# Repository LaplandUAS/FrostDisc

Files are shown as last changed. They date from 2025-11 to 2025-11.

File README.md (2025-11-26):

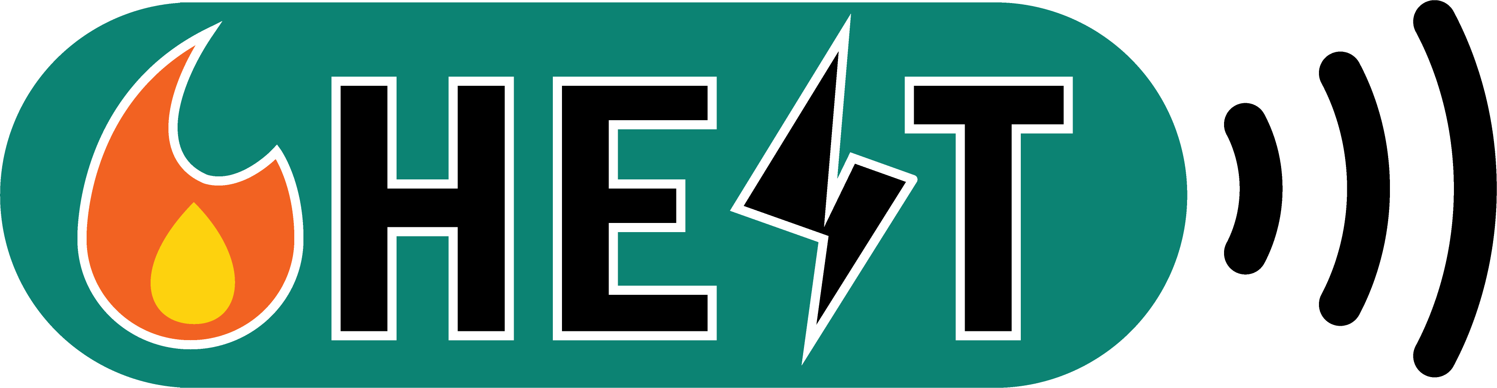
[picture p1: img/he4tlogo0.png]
He4T Logo Project logo

# FrostDisc
HE4T ForstDisc
Road embedded ultra-low power temperature gradient sensor built with wireless LoRaWAN technology. This repository contains the system firmware, and printed circuit board designs.
The device features:
* 4x [TMP117](https://www.ti.com/lit/ds/symlink/tmp117.pdf?ts=1762762775582) High-Accuracy temperature sensors.
* MultiTech [xDot](https://multitech.com/wp-content/uploads/86002182.pdf) LoRaWAN module.
* [MSP430G2231](https://www.ti.com/lit/ds/symlink/msp430g2231-q1.pdf?ts=1762703573675) microcontroller.

The device's energy source also features a battery pack and a super capacitor power reserve maintained by an [Epishine](https://www.epishine.com/) PV-cell. The assembly is embedded into a durable resin cast.

Mockup 3d render Frostdisc mockup

## Hardware setup
Required tools and hardware:
* Soldering iron
* USB-UART adapter
* MSP-FET programmer
* FrostDisc MK.4

### Radio
First, connect your USB-UART adapter to the edge connector on the FrostDisc MK.4 board. The edge is an [AVX10](https://datasheets.kyocera-avx.com/OpenEndedCardEdge_00-9159.pdf)-edge connector, but temporary soldering or pogo pins work fine too.
Follow this pinout (fig.1). The diagram shown connects to the top-layer of the edge connector.
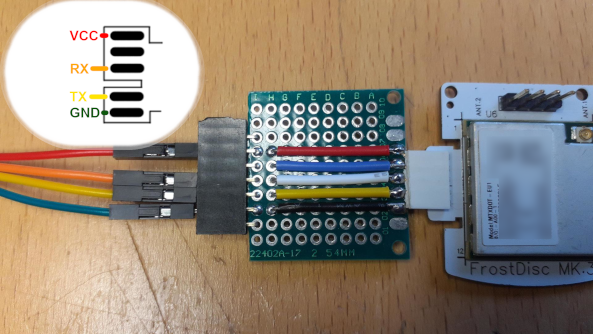
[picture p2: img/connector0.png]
UART connection AVX10 adapter board

Open a serial terminal software (Like PuTTY or CoolTerm), and connect to your your USB-UART adapter with these parameters:
| Parameter | Value |
| --- |:---:|
| Baudrate | 115200 |
| Data Bits | 8 |
| Parity | None |
| Stop Bits | 1 |

Confirm proper connection with:
```
>ATI
ATIMultiTech xDot
Firmware : 4.1.32-mbed60800
Library  : 4.1.30-mbed60800
MTS-Lora : 4.1.21-mbed60800

OK
```
> [!WARNING]
> Skip commands marked with '*' before writing parameters if you intend to test your connection manually first!
> Only apply these commands after you've checked your connection. The command order given below is is for bulk-programming without any manual testing.

Apply these parameters in this order:

| Parameter |  Description |
| --- |:---:|
| AT+DI? | DevEUI, write down for your LoRaWAN provider |
| AT+NA=<Your DevAddr> | Match with your LoRaWAN provider (HEX-tring) |
| AT+DSK=<Your AppSKey> | Match with your LoRaWAN provider (HEX-tring) |
| AT+NSK=<Your NSK> | Match with your LoRaWAN provider (HEX-tring) |
| AT+NJM=0 | Sets radio in ABP mode |
| AT+WP=6,0,1 | Sets wakeup pin * |
| AT+WM=1 | Sets wakeup mode to "On interrupt" * |
| ATE0 | Disable echo (optional) * |
| AT&W | Write parameters |
| ATZ | Soft reset |

Please refer to your LoRaWAN network service provider's instructions for pairing, or your gateway's user manual if you have your own.

Further information on the xDot AT-syntax can be found [here](https://multitech.com/wp-content/uploads/S000768-xDot-AT-Command-Guide.pdf).

You can manually test your connection with your LoRaWAN network of choice after configuring both ends by issuing the following AT command:

```
>AT+SENDB=DEADBEEF

OK
```
Note that in order to comply with EU868 restrictions, the transmission channel will be disabled for a few minutes after each `AT+SEND`.

### MCU

The MCU firmware is uploaded using an MSP-FET programmer for TexasInstruments MSP430-based microcontrollers. You can also use the debug-part of an MSP430 Launchpad development board.
The firmware is flashed using the CodeComposer Studio IDE.

Hook up your programmer of choice to the FrostDisc MK.4 header J.3 (fig.2)
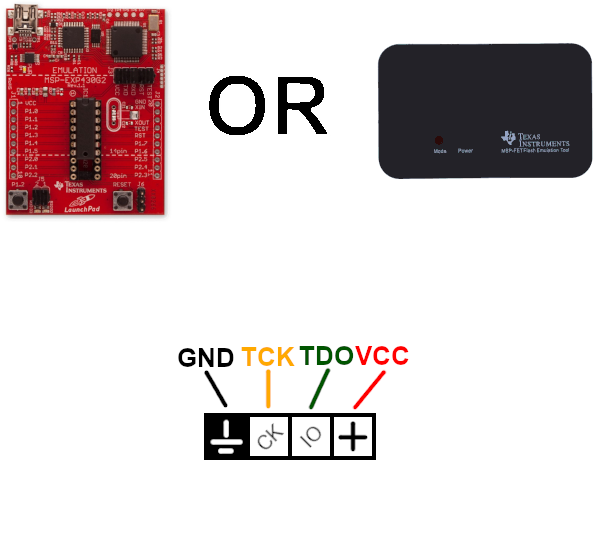
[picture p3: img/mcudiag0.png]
Programmer hookup MCU hookup diagram


In CodeComposer Studio, right click the active project and choose "Properties" (fig.3).

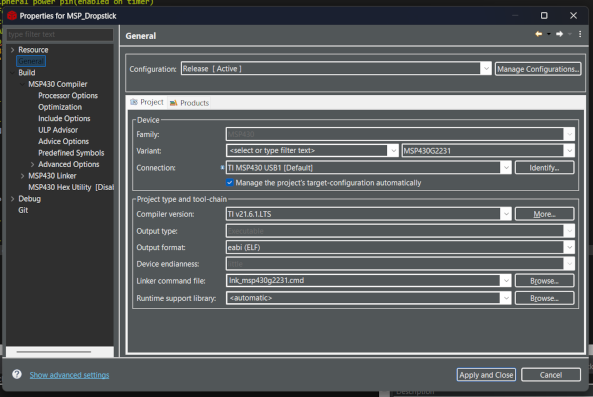
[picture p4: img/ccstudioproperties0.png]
Properties dialog Project properties

In the General settings, make sure that the device variant is "MSP430G2231". Then plug your programmer to your PC's USB-port and click "Identify". After the debugger identifies your programmer, it should show up in the drop down menu as `TI MSP430 Launchpad`, or `TI MSP430 USB1`.
For the linker command file, click browse and use the .cmd file provided in the 'src' directory. Click apply and Close.

Next, click the "Flash" icon on the top left corner (fig.4)

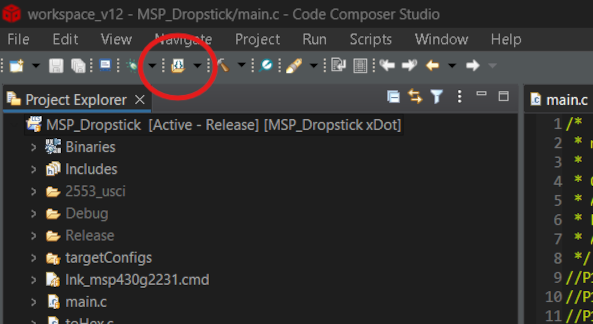
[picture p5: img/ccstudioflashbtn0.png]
Flash icon Click flash


Disconnect the programmer from the FrostDisck MK.4 once the firmware flash completes.

Next, solder a bridge over JP1, bridging it's topmpost and middle pad. Bridge the SJ2 pads (fig.5)

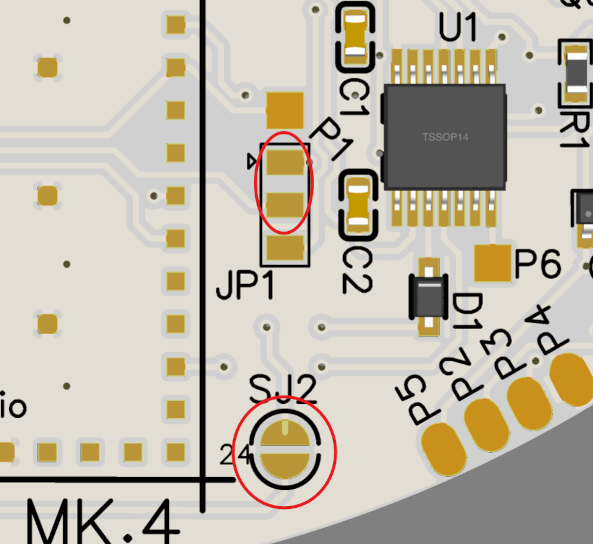
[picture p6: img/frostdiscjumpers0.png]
Solder jumpers Solder jumper bridges


### Initial tests
Before connecting the battery pack and temperature sensors, test if the system transmits data properly. Hook up a 3.3V power supply to the VCC and GND pins on the programming header and monitor your LoRaWAN gateway traffic. A small antenna may be needed for your radio if the RSSI is poor. After 10-minutes, you should be receiving the first packets from your device, which should be in a hexadecimal string format. The payload consists of 4 16-bit temperature readings followed by a single 16-bit value indicating the current battery charge.

Example payload:
`data: 0AFF0AFF0AFF0AFF3024D`
| Sensor 1 | Sensor 2 | Sensor3 | Sensor 4 | Core VCC |
| --- |:---:|:---:|:---:|:---:|
| 0AFF | 0AFF | 0AFF | 0AFF | 024D |

All the sensor readings will display the same value since they're not connected. For decoding payloads, we have ([a terminal program]repository here) for interfacing with an MQTT broker.

### Sensors and Battery pack

After confirming succesful downlink, disconnect the device from your power supply and solder thin 24-26AWG wires to the TMP117 sensor module (fig.6).

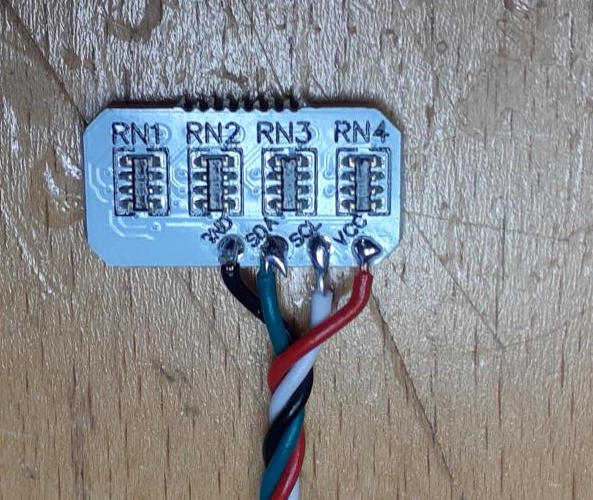
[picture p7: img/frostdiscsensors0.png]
TMP117 module TMP117 subassembly


Take note of the labels above the pads.
Solder to the corresponding pads on the FrostDisc MK.4 board (fig.7).

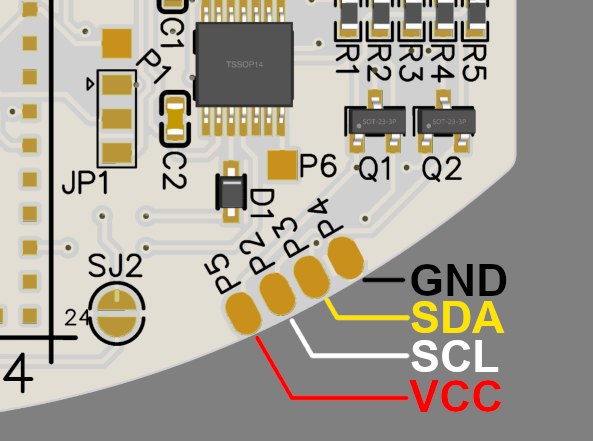
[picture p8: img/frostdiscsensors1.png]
I2C Bus TMP117 bus


Mount the battery pack on the J1 connector on the top edge of board, and attach the assembly to the 3D-printed cage.

---------


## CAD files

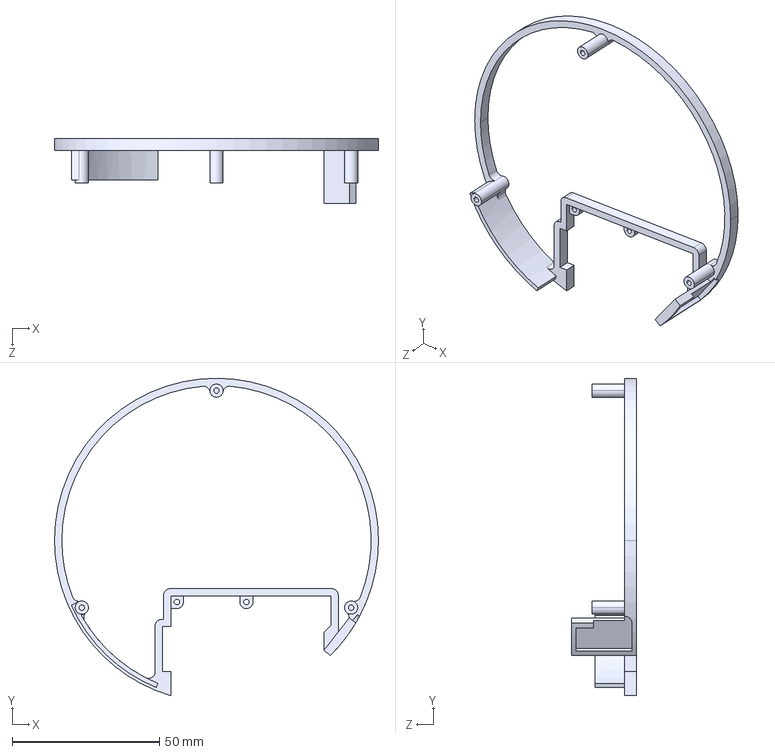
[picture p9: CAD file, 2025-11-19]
cad/cagehull.STEP
110.0 x 107.8 x 22.0 mm

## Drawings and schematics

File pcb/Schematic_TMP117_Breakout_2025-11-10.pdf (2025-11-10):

TMP117-0x48 | TMP117-0x49

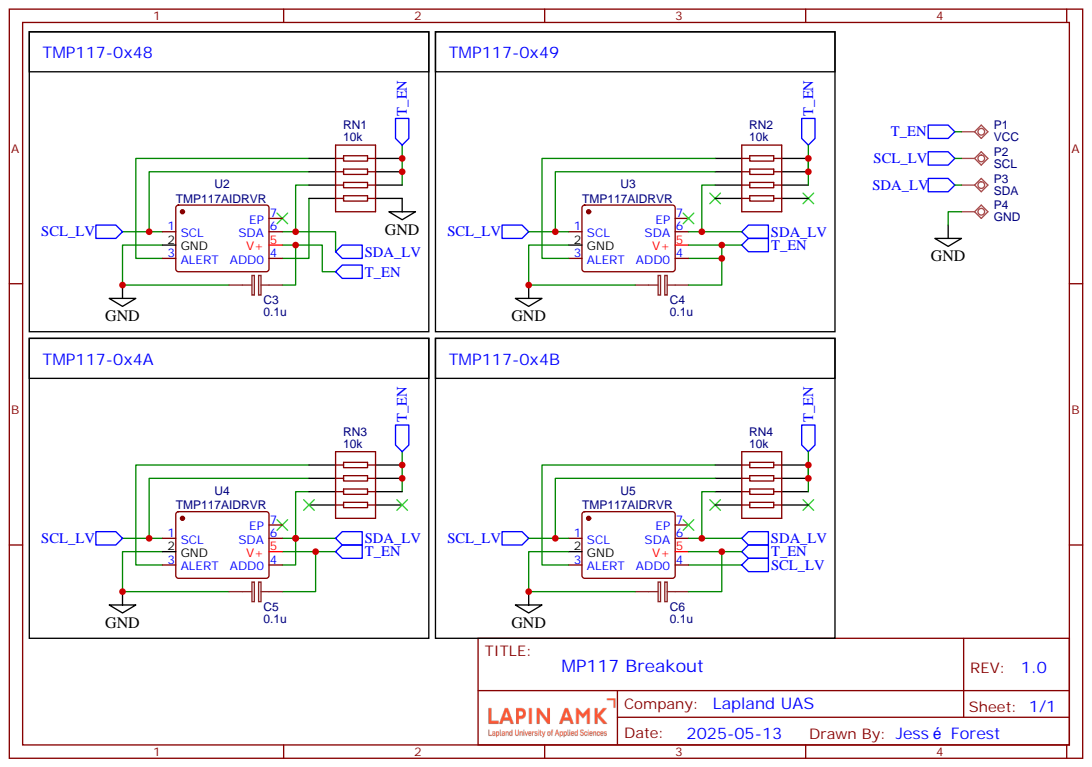
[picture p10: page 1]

Drawn By: Jess Forest

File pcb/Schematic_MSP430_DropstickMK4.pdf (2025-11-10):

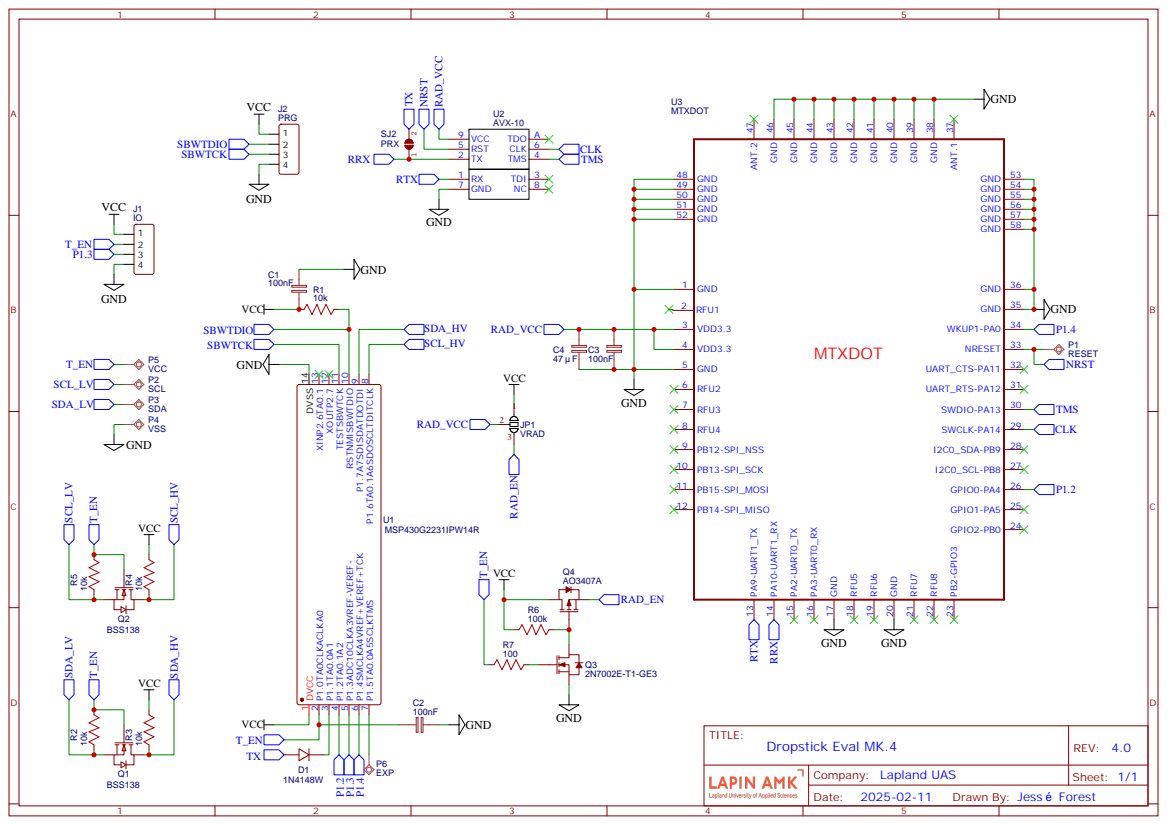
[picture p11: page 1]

Drawn By: Jess Forest

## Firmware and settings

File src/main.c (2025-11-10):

/*
 * main.c
 *
 * Created: 5.9.2023 12.28.35
 * Author : Jessé Forest
 */
 
//P1.0- General peripheral power pin(enabled on timer)
//P1.1- [RESERVED] for radio UART
//P1.2- Network status pin from radio(read on radio wakeup)
//P1.3- [RESERVED] ADC pin
//P1.4- Radio wakeup pin(enabled when radio needs to wake up)

#include <msp430g2231.h>
#include "usi_i2c.h"
#include "toHex.h"
#include "uart.h"

//------------------------------------------------------------------------------
// Macros
//------------------------------------------------------------------------------
#define ERROR_MARGIN        0x10                    // How many tries before giving up during various routines
#define MAX_ISR             0x1A                    // Counter limit (~20sec/inc) (1A is ~10min)
#define UARTCMD             "at+sendb="             // Serial message string
#define TERMINATION         "\r"                    // Serial termination string
#define SLEEPCMD            "at+sleep\r\0"          // Sleep command
#define JOINSTATUS          "at+njs\r\0"            // Join status
#define SENSORS             0x04                    // Number of connected sensors
#define TRIGGER_TEMP        4095                    // Temperature threshold (1280 for +10c, 4095 for +31c)

//------------------------------------------------------------------------------
// Global Variables
//------------------------------------------------------------------------------
const uint8_t tmp[] =                               // Sensor i2c address table (shifted left)
{
 0x90,                                              // 0x48
 0x92,                                              // 0x49
 0x94,                                              // 0x4A
 0x96                                               // 0x4B
};

uint16_t cfg[] =                                    // i2c configuration payload
{
 0x90,                                              // Device address (Doesn't matter here. Replaced procedurally)
 0x01,                                              // Command (Configure mode)
 0x0C,                                              // Command (Mode MSB)
 0x00                                               // Command (Mode LSB)
};

uint16_t pld[] =                                    // i2c temperature reading payload
{
 0x90,                                              // Device address (Doesn't matter here. Replaced procedurally)
 0x00,                                              // Command (Retrieve temperature)
 I2C_RESTART,                                       // Followed by i2c-restart
 0x91,                                              // Device address shifted by 1 (Doesn't matter here. Replaced procedurally)
 I2C_READ,                                          // Read MSB
 I2C_READ                                           // Read LSB
};

char status[5];                                     // Status buffer
uint8_t sbt = 0x00;                                 // Status byte
uint8_t i;                                          // Iterator
uint8_t isrC = (MAX_ISR-1);                         // Interrupt counter, make sure this is only a single cycle on first boot!
uint16_t rdx[SENSORS];                              // Sensor readings

//------------------------------------------------------------------------------
// Function prototypes
//------------------------------------------------------------------------------
void AdcInit(void);
void AdcStart(void);
void AdcDisable(void);
int GetAdcValue(void);

//------------------------------------------------------------------------------
// main()
//------------------------------------------------------------------------------
int main(void)
{
  BCSCTL1 = CALBC1_1MHZ;                            // Base clock to 1MHz
  BCSCTL1 |= DIVA_3;                                // ACLK/2
  BCSCTL3 |= LFXT1S_2;                              // ACLK = VLO

  WDTCTL = WDT_ADLY_1000;                           // Interval timer
  DCOCTL = CALDCO_1MHZ;                             // Calibrate clock

  IE1 |= WDTIE;                                     // Enable WDT interrupt

  P1OUT = 0xC0;                                     // All P1.x reset, P1.6 & P1.7 & P1.0 to out
  P1REN |= 0xC0;                                    // P1.6 & P1.7 Pullups
  P1SEL = UART_TXD;                                 // Timer function for TXD pin (P1.1)
  P1DIR = 0xFB;                                     // Set all pins to output on port 1
  P2OUT = 0x00;                                     // All P2.x reset
  P2SEL = 0x00;                                     // Don't configure anything (for now)
  P2DIR = 0xFF;                                     // Set all pins to output on port 2
  AdcInit();                                        // Initialize ADC

  __enable_interrupt();                             // Enable ISR
  while(1)                                          // Main loop
  {
    if(isrC++ == MAX_ISR)                           // Check Interrupt counter and increment
    {
        P1OUT |= BIT0;                              // Enable P1.0
        AdcStart();                                 // Start ADC conversion
        i2c_init(USIDIV_5, USISSEL_2);              // i2c USI registers
        __delay_cycles(1500);                       // Time for i2c to start...
        for(i=SENSORS; i-->0;)                      // Iterate through i2c devices
        {
            cfg[0] = tmp[i];                        // Set i2c slave address
            i2c_send_sequence(cfg, 4, 0 ,LPM3_bits);// Transmit payload over i2c
            while(!i2c_done());                     // Maybe more? 1500?
        }

        __delay_cycles(1500000);                    // Wait before writing to UART (The more you wait here the more accurate the i2c temperature reading becomes)
        for(i=SENSORS; i-->0;)
        {
            uint8_t b[2];                           // Response buffer
            pld[0] = tmp[i];                        // Set slave address
            pld[3] = tmp[i] + 1;                    // Set slave read address
            i2c_send_sequence(pld, 6, b, LPM3_bits);// Transmit payload over i2c
            while(!i2c_done());                     // Wait for bytes from slave
            __delay_cycles(1500);                   // Wait before writing to UART
            rdx[i]=((uint16_t)b[0]<<8)|b[1];        // Turn bytes to int and place in sensor reading array
            sbt = ((int16_t)rdx[i] <= TRIGGER_TEMP);// Threshold check

        }
        if(sbt)
        {
            P1OUT |= BIT4;                          // Enable wakeup pin
            TimerA_UART_init();                     // Start Timer_A UART
            i = ERROR_MARGIN;                       // Assign error margin to iterator
            do{
                TimerA_UART_print(JOINSTATUS);      // Transmit serial message. Try to wake up and update join status...
                __delay_cycles(80000);              // Waste some time trying
            }while(!(P1IN & BIT2));                 // Wait for NJS pin (or until tries run out)|| (i--) > 0
            TimerA_UART_print(UARTCMD);             // Transmit serial message
            for (i=SENSORS; i-->0;)                 // Iterate through every sensor
            {
                itohexa(status, rdx[i]);            // Write the 16-bit int to a buffer in HEX as ASCII
                //status[5] = '\0';                 // Ensure string termination with nullchar
                TimerA_UART_print(status);          // Add buffer to UART buffer
            }
            P1OUT &= ~BIT4;                         // Disable wakeup pin
            itohexa(status, GetAdcValue());         // Wait for ADC and read core voltage
            TimerA_UART_print(status);              // Write core voltage to UART
            TimerA_UART_print(TERMINATION);         // Transmit serial message
            do{
            TimerA_UART_print(SLEEPCMD);            // Put the radio to sleep shhh....
            __delay_cycles(80000);                  // Waste some time trying
            }while(P1IN & BIT2);                    // Wait for NJS pin (or until tries run out)|| (i--) > 0
            TimerA_UART_halt();                     // Halt TimerA UART
        }
        sbt = 0x00;                                 // Reset threshold check
        isrC = 0x00;                                // Reset interrupt counter
        P1OUT &= ~BIT0;                             // Disable P1.0
    }
    __bis_SR_register(LPM3_bits + GIE);             // Enter LPM3
  }
}

void AdcInit(void)
{
    ADC10AE0 = BIT5;                                // Set sampling pin
    ADC10CTL0 = SREF_1 + ADC10SHT_3;                // Enable ADC-core, 64 cycles sample time.
    ADC10CTL1 = INCH_5 + ADC10SSEL_2 + CONSEQ_0;    // Initialize ADC channel, clock source MCLK (At 1MHz), single sample
}

void AdcStart(void)
{
    ADC10CTL0 |= REFON + ADC10ON;                   // Turn on ADC and reference
    __delay_cycles(1000);                           // Give time for ADC to stabilize
    ADC10CTL0 |= ENC + ADC10SC;                     // Start ADC conversion
}

void AdcDisable(void)
{
    ADC10CTL0 &= ~ENC;                              // Stop conversion
    ADC10CTL0 &= ~(ADC10ON + REFON);                // Turn off ADC core and reference to save power
}

int GetAdcValue(void)
{
    while( ! (ADC10CTL0 & ADC10IFG));               // Wait for conversion ready flag
    ADC10CTL0 &= ~ADC10IFG;                         // Clear ready flag
    AdcDisable();                                   // Disable ADC core
    return ADC10MEM;                                // Return ADC reading
}

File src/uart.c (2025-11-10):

/*
 * uart.c
 *
 * Created: 22.8.2024 14.27.00
 * Author : Jessé Forest
 */

#include "uart.h"

uint16_t txData;                                    // UART internal variable for TX
//uint8_t rxBuffer;                                 // Incoming UART character buffer

//------------------------------------------------------------------------------
// Function configures Timer_A for full-duplex UART operation
//------------------------------------------------------------------------------
void TimerA_UART_init(void)
{
    TACCTL0 = OUT;                                  // Set TXD Idle as Mark = '1'
    TACCTL1 = SCS + CM1 + CAP + CCIE;               // Sync, Neg Edge, Capture, Int
    TACTL = TASSEL_2 + MC_2;                        // SMCLK, start in continuous mode
}

//------------------------------------------------------------------------------
// Function halts Timer_A
//------------------------------------------------------------------------------
void TimerA_UART_halt(void)
{
    TACTL &= ~(MC_2);                               // SMCLK, stop
}

//------------------------------------------------------------------------------
// Outputs one byte using the Timer_A UART
//------------------------------------------------------------------------------
void TimerA_UART_tx(unsigned char byte)
{
    while (TACCTL0 & CCIE);                         // Ensure last char got TX'd
    TACCR0 = TAR;                                   // Current state of TA counter
    TACCR0 += UART_TBIT;                            // One bit time till first bit
    TACCTL0 = OUTMOD0 + CCIE;                       // Set TXD on EQU0, Int
    txData = byte;                                  // Load global variable
    txData |= 0x100;                                // Add mark stop bit to TXData
    txData <<= 1;                                   // Add space start bit
}

//------------------------------------------------------------------------------
// Prints a string over using the Timer_A UART
//------------------------------------------------------------------------------
void TimerA_UART_print(char *string)
{
    while (*string) {
        TimerA_UART_tx(*string++);
    }
}

#pragma vector = WDT_VECTOR
__interrupt void watchdog_timer (void)
{
  __bic_SR_register_on_exit(LPM3_bits);             // Clear LPM3 bits from 0(SR)
}

#pragma vector = TIMERA0_VECTOR
__interrupt void Timer_A0_ISR(void)
{
    static unsigned char txBitCnt = 10;

    TACCR0 += UART_TBIT;                            // Add Offset to CCRx
    if (txBitCnt == 0) {                            // All bits TXed?
        TACCTL0 &= ~CCIE;                           // All bits TXed, disable interrupt
        txBitCnt = 10;                              // Re-load bit counter
    }
    else {
        if (txData & 0x01) {
          TACCTL0 &= ~OUTMOD2;                      // TX Mark '1'
        }
        else {
          TACCTL0 |= OUTMOD2;                       // TX Space '0'
        }
        txData >>= 1;
        txBitCnt--;
    }
}
